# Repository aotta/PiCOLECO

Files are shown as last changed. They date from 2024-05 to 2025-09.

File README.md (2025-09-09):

# PiCOLECO
Colecovision flash multicart based on Pico clone

**NEW** version 1.0a uploaded with partial support for Megacart switch banking roms up to 128kb

version 1.0c uploaded (fixed sprite bug in Pac-Man Compilation), porting to SDK 2.2 in progress

PiCOLECO is a multicart DIY yourself based on cheap "purple" Raspberry Pi Pico clone.
It should works for all roms up to 32k, but there's no enough RAM on Pico to handle 128k or larger multirom.

**WARNING!** "purple" Pico has not the same pinout of original Raspberry "green" ones, you MUST use the clone or you may damage your hardware.

**NOTE** FAT FS used for flash file management is quite simple, you can't use FILENAME LONGER THAN 32 BYTES INCLUDED SUFFIX!!!!! 
PLEASE RENAME YOUR BIN FILES OR THE GAMES WON'T START AT ALL!!!

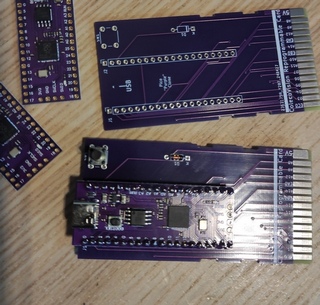
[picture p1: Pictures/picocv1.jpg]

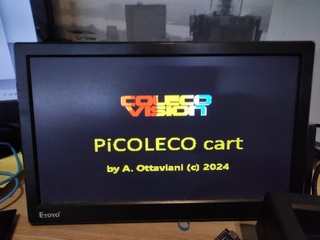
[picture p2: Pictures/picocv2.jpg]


Kicad project and gerbers files for the pcb are in the PCB folder, you need only a diode and a push buttons for resetting the cart if needed or want restart. 
Add you pico clone, and flash the firmware ".uf2" in the Pico by connecting it while pressing button on Pico and drop it in the opened windows on PC.
After flashed with firmware, and every time you have to change your ROMS repository, you can simply connect the Pico to PC and drag&drop "BIN" files  into.

More info on AtariAge forum: https://forums.atariage.com/topic/366660-picoleco-a-diy-multicart-for-colecovision/

Even if the diode should protect your console, **DO NOT CONNECT PICO WHILE INSERTED IN A POWERED ON CONSOLE!**

## Credits
Thank to Robin Robin Edwards and his A8PicoCart (https://github.com/robinhedwards/A8PicoCart), i found very smart his way to manage the Flash RAM and the USB updates, so i admit i took large parte of his code for it!.
I used also the new and fantastic CVBasic for writing menu and file selector in Colecovision, thank to Oscar Toledo (https://nanochess.org/) for creating it.




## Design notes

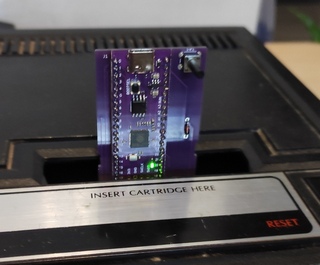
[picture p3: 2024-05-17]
Pictures/picocv4.jpg

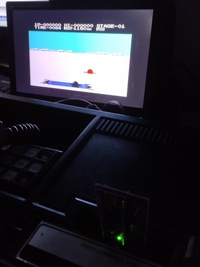
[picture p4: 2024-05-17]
Pictures/picocv5.jpg

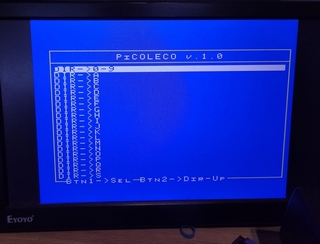
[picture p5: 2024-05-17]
Pictures/picocv3.jpg

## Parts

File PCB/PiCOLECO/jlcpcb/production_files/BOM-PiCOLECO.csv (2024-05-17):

Comment | Designator | Footprint | LCSC
CVS-Card | X1 | Coleco_Expansion_Card
SW_Push | SW1 | SW_PUSH_6mm
Conn_01x20 | J2 | PinSocket_1x20_P2.54mm_Vertical
Conn_01x20 | J1 | PinSocket_1x20_P2.54mm_Vertical
Diode | D1 | D_DO-35_SOD27_P7.62mm_Horizontal

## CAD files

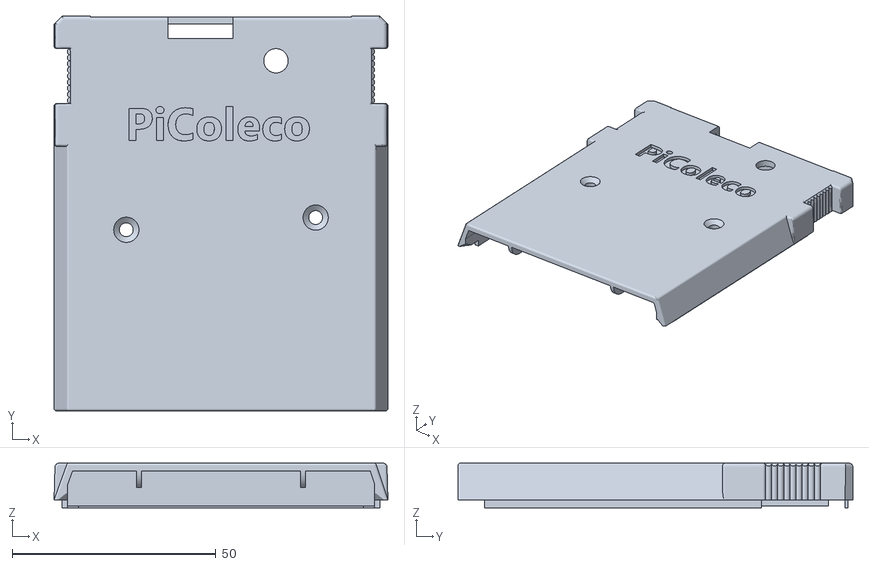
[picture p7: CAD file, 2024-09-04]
3DModel/PiColeco_cart-Top (Meshed).stl
82.0 x 97.0 x 11.0

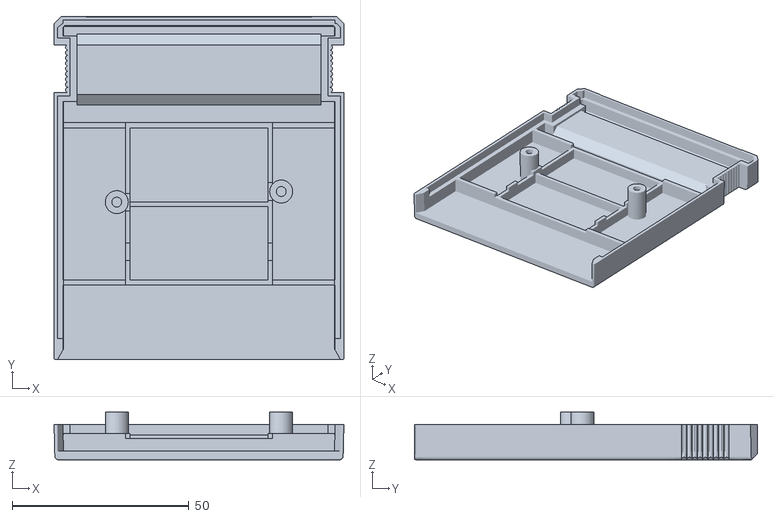
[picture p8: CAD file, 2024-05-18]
3DModel/PiColeco_cart-Bot (Meshed).stl
82.0 x 97.0 x 13.5

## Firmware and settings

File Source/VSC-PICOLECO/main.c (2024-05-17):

/*
//                       PiCOLECO MultiCART by Andrea Ottaviani 2024
//
//  COLECOVISION  multicart based on Raspberry Pico board -
//
//  More info on https://github.com/aotta/ 
//
//   parts of code are directly from the A8PicoCart project by Robin Edwards 2023
//  
//   Needs to be a release NOT debug build for the cartridge emulation to work
// 
//   Edit myboard.h depending on the type of flash memory on the pico clone//
//
//   v. 1.0 2024-05-15 : Initial version for Pi Pico 
//
*/



#include <stdio.h>
#include <string.h>

#include "pico/stdlib.h"
#include "pico/time.h"
#include "tusb.h"

#include "coleco_cart.h"
#include "fatfs_disk.h"

//void cdc_task(void);


//--------------------------------------------------------------------+
// USB CDC
//--------------------------------------------------------------------+
void cdc_task(void)
{
  // connected() check for DTR bit
  // Most but not all terminal client set this when making connection
  // if ( tud_cdc_connected() )
  {
    // connected and there are data available
    if ( tud_cdc_available() )
    {
      // read data
      char buf[64];
      uint32_t count = tud_cdc_read(buf, sizeof(buf));
      (void) count;

      // Echo back
      // Note: Skip echo by commenting out write() and write_flush()
      // for throughput test e.g
      //    $ dd if=/dev/zero of=/dev/ttyACM0 count=10000
      tud_cdc_write(buf, count);
      tud_cdc_write_flush();
    }
  }
}

// Invoked when cdc when line state changed e.g connected/disconnected
void tud_cdc_line_state_cb(uint8_t itf, bool dtr, bool rts)
{
  (void) itf;
  (void) rts;

  // TODO set some indicator
  if ( dtr )
  {
    // Terminal connected
  }else
  {
    // Terminal disconnected
  }
}

// Invoked when CDC interface received data from host
void tud_cdc_rx_cb(uint8_t itf)
{
  (void) itf;
}


int main(void)
{
   tusb_init();
   stdio_init_all();   // for serial output, via printf()
   
    tud_init(BOARD_TUD_RHPORT);
    gpio_init_mask(FLAG_MASK);
    gpio_set_dir_in_masked(FLAG_MASK);
   
    while(1) {          
      
    while (to_ms_since_boot(get_absolute_time()) < 200)
    {
      if ((gpio_get_all()&FLAG_MASK))
        coleco_cart_main();
    }

     
       // init device stack on configured roothub port
       // we are presumably powered from USB
       // enter USB mass storage mode
     //  tud_init(BOARD_TUD_RHPORT);
     //  stdio_init_all();   // for serial output, via printf()
     //  printf("Start\n");

       while (1) {
          tud_task(); // tinyusb device task
         
          cdc_task();
       }
    
    }
   return 0;
}

//--------------------------------------------------------------------+
// Device callbacks
//--------------------------------------------------------------------+

// Invoked when device is mounted
void tud_mount_cb(void)
{
  printf("Device mounted\n"); 
  if (!mount_fatfs_disk())
    create_fatfs_disk();
}

// Invoked when device is unmounted
void tud_umount_cb(void)
{
  printf("Device unmounted\n");  
}

// Invoked when usb bus is suspended
// remote_wakeup_en : if host allow us  to perform remote wakeup
// Within 7ms, device must draw an average of current less than 2.5 mA from bus
void tud_suspend_cb(bool remote_wakeup_en)
{
  (void) remote_wakeup_en;
//  blink_interval_ms = BLINK_SUSPENDED;
}

// Invoked when usb bus is resumed
void tud_resume_cb(void)
{
//  blink_interval_ms = BLINK_MOUNTED;
}

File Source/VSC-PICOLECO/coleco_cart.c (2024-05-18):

/*
//                       PiCOLECO MultiCART by Andrea Ottaviani 2024
//
//  COLECOVISION  multicart based on Raspberry Pico board -
//
//  More info on https://github.com/aotta/ 
//
//   parts of code are directly from the A8PicoCart project by Robin Edwards 2023
//  
//   Needs to be a release NOT debug build for the cartridge emulation to work
// 
//   Edit myboard.h depending on the type of flash memory on the pico clone//
//
//   v. 1.0 2024-05-15 : Initial version for Pi Pico 
//
*/


#include <stdio.h>
#include <stdlib.h>
#include <string.h>
#include "pico/multicore.h"
#include "hardware/gpio.h"
#include "pico/platform.h"
#include "pico/stdlib.h"
#include "hardware/vreg.h"
#include "pico/divider.h"
#include "hardware/flash.h"
#include "hardware/sync.h"


#include "rom.h"

#include "tusb.h"
#include "ff.h"
#include "fatfs_disk.h"

// Pico pin usage definitions

#define A0_PIN    0
#define A1_PIN    1
#define A2_PIN    2
#define A3_PIN    3
#define A4_PIN    4
#define A5_PIN    5
#define A6_PIN    6
#define A7_PIN    7
#define A8_PIN    8
#define A9_PIN    9
#define A10_PIN  10
#define A11_PIN  11
#define A12_PIN  12
#define A13_PIN  13
#define A14_PIN  14
#define A15_PIN  15  // non collegato
#define D0_PIN   16
#define D1_PIN   17
#define D2_PIN   18
#define D3_PIN   19
#define D4_PIN   20
#define D5_PIN   21
#define D6_PIN   22
#define D7_PIN   23
#define FCE0_PIN 24
#define FCE1_PIN 25
#define FCE2_PIN 26
#define FCE3_PIN 27

// Pico pin usage masks

#define A0_PIN_MASK     0x00000001L
#define A1_PIN_MASK     0x00000002L
#define A2_PIN_MASK     0x00000004L
#define A3_PIN_MASK     0x00000008L
#define A4_PIN_MASK     0x00000010L
#define A5_PIN_MASK     0x00000020L
#define A6_PIN_MASK     0x00000040L
#define A7_PIN_MASK     0x00000080L
#define A8_PIN_MASK     0x00000100L
#define A9_PIN_MASK     0x00000200L
#define A10_PIN_MASK    0x00000400L
#define A11_PIN_MASK    0x00000800L
#define A12_PIN_MASK    0x00001000L
#define A13_PIN_MASK    0x00002000L
#define A14_PIN_MASK    0x00004000L
#define A15_PIN_MASK    0x00008000L // NON COLLEGETO
#define D0_PIN_MASK     0x00010000L
#define D1_PIN_MASK     0x00020000L
#define D2_PIN_MASK     0x00040000L
#define D3_PIN_MASK     0x00080000L
#define D4_PIN_MASK     0x00100000L
#define D5_PIN_MASK     0x00200000L  // gpio 21
#define D6_PIN_MASK     0x00400000L
#define D7_PIN_MASK     0x00800000L

#define FCE0_PIN_MASK   0x01000000L //gpio 24 enable $8000
#define FCE1_PIN_MASK   0x02000000L //gpio 25 enable $a000
#define FCE2_PIN_MASK   0x04000000L //gpio 26 enable $c000
#define FCE3_PIN_MASK   0x08000000L //gpio 27 enable $e000

// Aggregate Pico pin usage masks
#define ALL_GPIO_MASK  	0x0FFF7FFFL
#define BUS_PIN_MASK    0x00007FFFL
#define DATA_PIN_MASK   0x00FF0000L
#define FLAG_MASK       0x0F000000L
#define ROM_MASK ( MREQ_PIN_MASK  ) 
#define ALWAYS_IN_MASK  (BUS_PIN_MASK | FLAG_MASK)
#define ALWAYS_OUT_MASK (DATA_PIN_MASK )


#define FCE0   0b0001  //1
#define FCE1   0b0010  //2
#define FCE2   0b0100  //4
#define FCE3   0b1000  //8

uint32_t pageLookup[16]={0,0,0,0,0,0,0,0,0,0,0,0,0,0,0,0};

#define SET_DATA_MODE_OUT   gpio_set_dir_out_masked(DATA_PIN_MASK)
#define SET_DATA_MODE_IN    gpio_set_dir_in_masked(DATA_PIN_MASK)
// We're going to erase and reprogram a region 256k from the start of flash.
// Once done, we can access this at XIP_BASE + 256k.


char RBLo,RBHi;
#define BINLENGTH  65536L
unsigned char ROM[BINLENGTH];
unsigned char RAM[1024];
unsigned char files[256*256] = {0};
unsigned char nomefiles[32*25] = {0};
char curPath[256] = "";
char path[256];
int fileda=0,filea=0;
volatile char cmd=0;
char errorBuf[40];
bool cmd_executing=false;
char gamechoosen=1;


////////////////////////////////////////////////////////////////////////////////////
//                     Error(N)
////////////////////////////////////////////////////////////////////////////////////
void error(int numblink){
  while(1){
	gpio_set_dir(PICO_DEFAULT_LED_PIN,GPIO_OUT);
    
    for(int i=0;i<numblink;i++) {
      gpio_put(PICO_DEFAULT_LED_PIN,true);
      sleep_ms(600);
      gpio_put(PICO_DEFAULT_LED_PIN,false);
      sleep_ms(500);
    }
  sleep_ms(2000);
  }
}

/*
 Theory of Operation
 -------------------
 Colecovision sends command to mcu on cart by writing to 6000 (CMD), 6001 (parameter) and menu (6002-6641) 
 Colecovision must be running from RAM when it sends a command, since the mcu on the cart will
 go away at that point. Colecovision polls 6001 until it reads $1.
*/

void __not_in_flash_func(core1_main()) {

    uint32_t addr;
    char dataWrite=0;
    uint32_t pins;

	multicore_lockout_victim_init();	

   
    gpio_set_dir_in_masked(ALWAYS_IN_MASK);
    // Initial conditions
    SET_DATA_MODE_IN;
  
  while (gamechoosen)
  {
	pins=gpio_get_all();
	
	if (((pins & FLAG_MASK)>>FCE0_PIN)!=0b1111) {
	//	pins=gpio_get_all(); // re-read for Coleco;
		int8_t PAGE=pins & FLAG_MASK;
    //	addr = (pins & BUS_PIN_MASK) | pageLookup[PAGE];
		addr = (pins & BUS_PIN_MASK);
	 	if ((addr >= 0x7000)) {		
			if (addr>=0x7100) {
				SET_DATA_MODE_OUT;
    			gpio_put_masked(DATA_PIN_MASK,ROM[addr]<<16);
    			SET_DATA_MODE_IN;
				ROM[0xf001]=addr-0x7100;
			
			} else {	
		    SET_DATA_MODE_OUT;
    		gpio_put_masked(DATA_PIN_MASK,ROM[addr]<<16);
    		SET_DATA_MODE_IN;
			ROM[0xf000]=addr-0x7000;
			}
   	 	} else {
			SET_DATA_MODE_OUT;
    		gpio_put_masked(DATA_PIN_MASK,ROM[addr]<<16);
    		SET_DATA_MODE_IN;
 	
		}
	} 	
  }	
   while (1)
  {
	pins=gpio_get_all();

	if (((pins & FLAG_MASK)>>FCE0_PIN)!=0b1111) {
	//	pins=gpio_get_all(); // re-read for Coleco;
		int8_t PAGE=pins & FLAG_MASK;
		addr = (pins & BUS_PIN_MASK);
		SET_DATA_MODE_OUT;
   		gpio_put_masked(DATA_PIN_MASK,ROM[addr]<<16);
   		SET_DATA_MODE_IN;
	} 	
  }	  
}
////////////////////////////////////////////////////////////////////////////////////
//                     MENU Reset
////////////////////////////////////////////////////////////////////////////////////    

void reset() {
   
 //multicore_lockout_start_blocking();	

  while (((gpio_get_all() & FLAG_MASK)>>FCE0_PIN)!=0b1111);
  SET_DATA_MODE_OUT;
  gpio_put_masked(DATA_PIN_MASK,0xc7<<16);
  sleep_ms(30);
  SET_DATA_MODE_IN;

  while (((gpio_get_all() & FLAG_MASK)>>FCE0_PIN)!=0b1111);
  SET_DATA_MODE_OUT;
  gpio_put_masked(DATA_PIN_MASK,0xc7<<16);
  sleep_ms(30);
  SET_DATA_MODE_IN;
  
  //multicore_lockout_end_blocking();
/*
  while (((gpio_get_all() & FLAG_MASK)>>FCE0_PIN)!=0b1111);
  SET_DATA_MODE_OUT;
  gpio_put_masked(DATA_PIN_MASK,0xc7<<16);
  sleep_ms(3);
  SET_DATA_MODE_IN;
*/


}       

////////////////////////////////////////////////////////////////////////////////////

typedef struct {
	char isDir;
	char filename[13];
	char long_filename[32];
	char full_path[210];
} DIR_ENTRY;	// 256 bytes = 256 entries in 64k

int num_dir_entries = 0; // how many entries in the current directory
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

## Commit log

2024-05-19 some fixes
    [PiColeco_cart-Top (Meshed).stl]
2024-06-16 megacart support
    Partial support for megacart switch banking up to 128k rom
2024-06-30 Add files via upload
    Bug fixed for Activision Bank switching - but not yet fully 100% working
2024-09-04 Add files via upload
    fixed button hole position
    [PiColeco_cart-Top (Meshed).stl]
